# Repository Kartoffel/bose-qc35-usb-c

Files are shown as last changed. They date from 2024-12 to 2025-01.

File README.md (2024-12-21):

# Bose QC35 USB-C mod

This is a repository holding details of how to modify the Bose QC35 headphones
to support USB charging/firmware update over USB-C, rather than the archaic
micro-USB connector. This mod works with both QC35 I and QC35 II versions of the
headphones.

## Disclaimer

This mod involves opening and disassembing your rather expensive headphone that
you probably really like using. There is a not insignificant chance of you could
damaging your headphones in this process. Keep that in mind before you start.
For best chances of success: take your time, work on a well lit anti-static
workspace.

We don't take any responsibility nor liability for damage when using any
information provided in this repository.

Good luck!

## Quick start

### [View schematic and layout online using KiCanvas!](https://kicanvas.org/?github=https%3A%2F%2Fgithub.com%2Fjamesturton%2Fbose-qc35-usb-c)

## How to get started

You will be replacing the USB daughter board with a new one featuring a USB-C
connector. This means there is no modification to the existing USB daughter
board, thus (other than enlarging the hole in the plastic housing) this process
is easily reversible.

Assembled PCB

The exisiting USB daughter board has been reverse-engineered and it's schematic
has been drawn using KiCad 8.0. All of the source files are provided here if you
would like to make any more changes, however the [gerber files](https://github.com/jamesturton/bose-qc35-usb-c/blob/main/gerber.zip?raw=true)
are also provided which can be sent directly to the PCB fab of your choosing.
The thickness of the PCB should be 1mm.

Once you have the sent off for the PCB to be manufactured, you will need to
order the parts to populate the PCB with. Some PCB fabs offer assembly also, but
I am not sure if any 'budget' PCB fab offer double-sided assembly services.
An 'interactive BoM' can be found in the 'bom' directory.

## Assembly

Assembly of this PCB is not for the faint of heart. A decent soldering/re-work
station, microscope and experience with soldering fine-pitch components are all
recommended. The molex connector for the flat-flex to the main board has a pin
pitch of 0.4mm. I recommend starting with the passives and LEDs first, working
up to the larger ICs and connectors later.

Once you have assembled the PCB you can start to disassemble your headphones to
replace the USB daughter board:
* Remove the foam earcup and foam sheet across the speaker grill on the right
ear phone.
* Remove the three philips-0 screws holding the metal outer shell in place. This
reveals the USB daughter board and mainboard.
* Cut away the silastic holding the cable for the mainboard.
* Remove the mainboard and LED/button board cables from the USB board.
* Unscrew the two philips-0 screws holding down the USB board to remove it.

With the old USB board removed it is now time for the most destructive step. You
will need to enlarge the hole in the plastic housing for the larger USB-C
connector to exit through. This can be done easily with a rotary tool, or less
easily with a small file. Keep checking the fit with the USB-C connector so the
hole is not made too big.

Reassemble the headphones by reversing the steps above.

New PCB in place

### Enjoy using your modded headphones!

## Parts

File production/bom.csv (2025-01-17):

Designator | Footprint | Quantity | Value | LCSC Part #
C1 | 0402 | 1 | 4u7 | C23733
C2 | 0402 | 1 | 1u | C52923
D1 | 0603 | 1 | ORH-G36G | C7371905
D2 | 0603 | 1 | ORH-R36G | C2286
D3 | 0603 | 1 | ORH-W46G | C2290
D4 | 0603 | 1 | ORH-B36G | C193191
D5 | SOT-323_SC-70 | 1 | BAT54CW | C22392482
FB1 | 0402 | 1 | 330R @ 100MHz | C160975
J1 | Molex_SlimStack_502426-2010_2x10_P0.40mm_Vertical | 1 | 502426-2030 | C563934
J2 | USB_C_Receptacle_Molex_2171790001 | 1 | 2171790001 | C29780877
J3 | TE_0-1734839-5_1x05-1MP_P0.5mm_Horizontal | 1 | 51281-0598 | C18548053
Q1 | SOT-723 | 1 | BC846BM3T5G | C232536
R1, R17, R18, R19, R2, R3, R4 | 0402 | 7 | CG0402MLC-05LG | C711709
R10 | 0402 | 1 | 510R | C25123
R11, R14, R15, R16 | 0402 | 4 | 1k | C11702
R12, R13 | 0402 | 2 | 5k1 | C25905
R20, R6 | 0402 | 2 | 10k | C25744
R22 | 0402 | 1 | 220k | C25767
R7 | 0402 | 1 | 7k5 | C137934
R8 | 0402 | 1 | 3k9 | C131467
R9 | 0402 | 1 | 1k2 | C25862
U1 | WSON-6-1EP_2x2mm_P0.65mm_EP1x1.6mm | 1 | TPS25200 | C128401

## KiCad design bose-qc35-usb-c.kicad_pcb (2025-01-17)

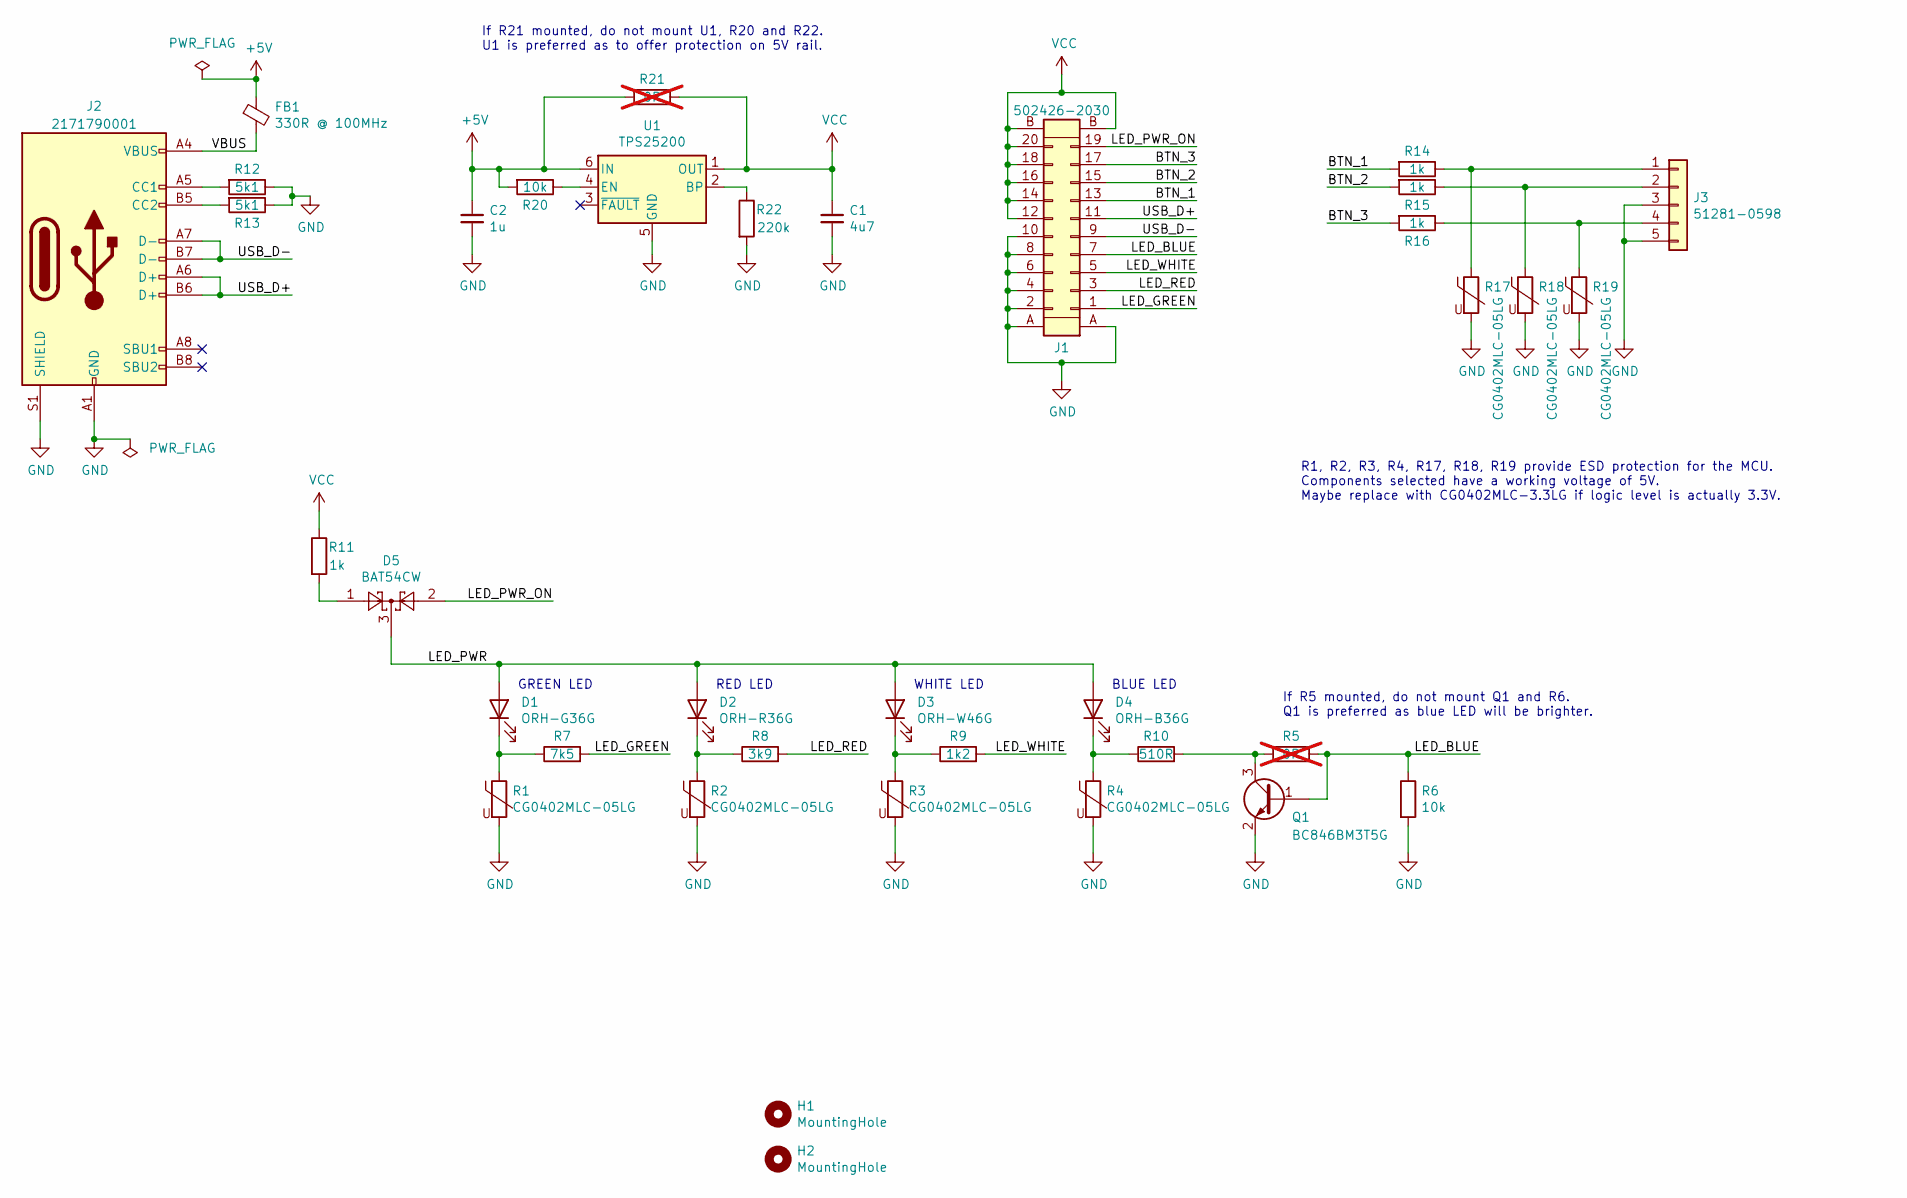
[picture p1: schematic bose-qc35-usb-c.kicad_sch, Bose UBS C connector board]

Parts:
C1: 4u7; C_0402_1005Metric; LCSC C23733
C2: 1u; C_0402_1005Metric; LCSC C52923
D1: ORH-G36G; LED_0603_1608Metric; LCSC C7371905
D2: ORH-R36G; LED_0603_1608Metric; LCSC C2286
D3: ORH-W46G; LED_0603_1608Metric; LCSC C2290
D4: ORH-B36G; LED_0603_1608Metric; LCSC C193191
D5: BAT54CW; SOT-323_SC-70; LCSC C22392482
FB1: 330R @ 100MHz; Fuse_0402_1005Metric; LCSC C160975
H1, H2: MountingHole; MountingHole_2.1mm
J1: 502426-2030; Molex_SlimStack_502426-2010_2x10_P0.40mm_Vertical; LCSC C563934
J2: 2171790001; USB_C_Receptacle_Molex_2171790001; LCSC C29780877
J3: 51281-0598; TE_0-1734839-5_1x05-1MP_P0.5mm_Horizontal; LCSC C18548053
Q1: BC846BM3T5G; SOT-723; LCSC C232536
R1, R2, R3, R4, R17, R18, R19: CG0402MLC-05LG; R_0402_1005Metric; LCSC C711709
R5, R21: 0R; R_0402_1005Metric; not fitted
R6, R20: 10k; R_0402_1005Metric; LCSC C25744
R7: 7k5; R_0402_1005Metric; LCSC C137934
R8: 3k9; R_0402_1005Metric; LCSC C131467
R9: 1k2; R_0402_1005Metric; LCSC C25862
R10: 510R; R_0402_1005Metric; LCSC C25123
R11, R14, R15, R16: 1k; R_0402_1005Metric; LCSC C11702
R12, R13: 5k1; R_0402_1005Metric; LCSC C25905
R22: 220k; R_0402_1005Metric; LCSC C25767
U1: TPS25200; WSON-6-1EP_2x2mm_P0.65mm_EP1x1.6mm; LCSC C128401

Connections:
+5V: C2.1, FB1.1, R20.2, R21.2, U1.6 (IN)
/BTN_1: J1.13, R14.2
/BTN_2: J1.15, R15.2
/BTN_3: J1.17, R16.2
/LED_BLUE: J1.7, Q1.1 (B), R5.2, R6.1
/LED_GREEN: J1.1, R7.2
/LED_PWR: D1.2 (A), D2.2 (A), D3.2 (A), D4.2 (A), D5.3
/LED_PWR_ON: D5.2, J1.19
/LED_RED: J1.3, R8.2
/LED_WHITE: J1.5, R9.2
/USB_D+: J1.11, J2.A6 (D+), J2.B6 (D+)
/USB_D-: J1.9, J2.A7 (D-), J2.B7 (D-)
/VBUS: FB1.2, J2.A4 (VBUS), J2.A9 (VBUS), J2.B4 (VBUS), J2.B9 (VBUS)
GND: C1.2, C2.2, J1.2, J1.4, J1.6, J1.8, J1.10, J1.A, J2.A1 (GND), J2.A12 (GND), J2.B1 (GND), J2.B12 (GND), J2.S1 (SHIELD), J3.3, J3.5, Q1.2 (E), R1.2, R2.2, R3.2, R4.2, R6.2, R12.1, R13.1, R17.2, R18.2, R19.2, R22.2, U1.5 (GND), U1.7 (GND)
unnamed: D1.1 (K), R1.1, R7.1
unnamed: D2.1 (K), R2.1, R8.1
unnamed: D3.1 (K), R3.1, R9.1
unnamed: D4.1 (K), R4.1, R10.1
unnamed: D5.1, R11.2
unnamed: J2.A5 (CC1), R12.2
unnamed: J2.B5 (CC2), R13.2
unnamed: J3.1, R14.1, R17.1
unnamed: J3.2, R15.1, R18.1
unnamed: J3.4, R16.1, R19.1
unnamed: Q1.3 (C), R5.1, R10.2
unnamed: R22.1, U1.2 (BP)
unnamed: R20.1, U1.4 (EN)
VCC: C1.1, J1.12, J1.14, J1.16, J1.18, J1.20, J1.B, R11.1, R21.1, U1.1 (OUT)

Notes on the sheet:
R1, R2, R3, R4, R17, R18, R19 provide ESD protection for the MCU. Components selected have a working voltage of 5V. Maybe replace with CG0402MLC-3.3LG if logic level is actually 3.3V.
WHITE LED
GREEN LED
RED LED
If R21 mounted, do not mount U1, R20 and R22. U1 is preferred as to offer protection on 5V rail.
If R5 mounted, do not mount Q1 and R6. Q1 is preferred as blue LED will be brighter.
BLUE LED

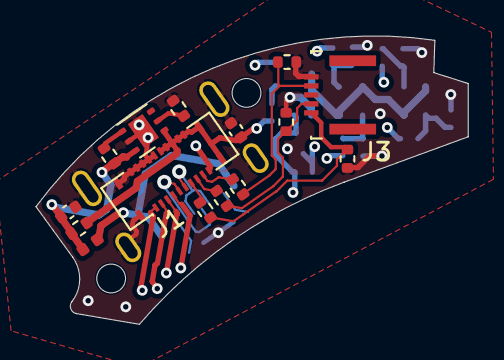
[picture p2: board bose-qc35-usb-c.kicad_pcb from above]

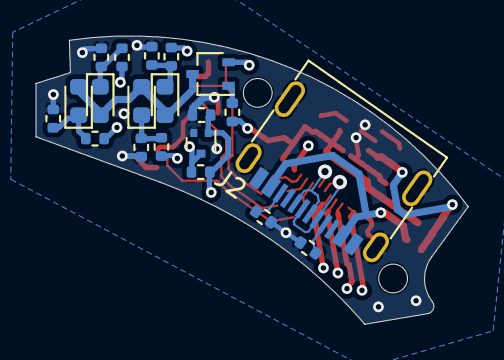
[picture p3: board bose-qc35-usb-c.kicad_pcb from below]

Board: 4 copper layers, 24.0 x 16.0 mm, 37 parts (20 on the bottom side), 28 nets.

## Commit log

2024-12-21 Convert to KiCad 8.0
    [bose-qc35-usb-c.kicad_pcb, bose-qc35-usb-c.kicad_sch]
2024-12-21 Fix Molex USB-C connector footprint
    Update part origin and use correct 3D model
    [bose-qc35-usb-c.kicad_pcb]
2024-12-21 Fix silkscreen
    Remove excess
    [bose-qc35-usb-c.kicad_pcb]
2025-01-17 Update DNP components
    [bose-qc35-usb-c.kicad_pcb, bose-qc35-usb-c.kicad_sch]
2025-01-17 Remove old production files
    [bose-qc35-usb-c-B_Cu.gbr, bose-qc35-usb-c-B_Mask.gbr, bose-qc35-usb-c-Edge_Cuts.gbr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]
2025-01-17 Add JLC production files
    [bom.csv, designators.csv, positions.csv]

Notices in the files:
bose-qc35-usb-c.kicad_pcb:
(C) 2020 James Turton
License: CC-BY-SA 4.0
